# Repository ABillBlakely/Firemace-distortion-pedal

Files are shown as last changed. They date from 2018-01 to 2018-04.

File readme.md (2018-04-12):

# Firemace

## The Project:

Distortion pedals are one of the most basic and most used types of guitar effects pedal, and this project serves as a good introduction into the world of guitar effects building.
The Firemace is based on [Robin Tomtlunds Red Fuzz](http://www.generalguitargadgets.com/effects-projects/distortion/red-fuzz/) design.
This project is designed to be an easy to build kit with possibility of modification and customization.

## The Objective:

Learn the inner workings of distortion pedals, and the common techniques involved in building most guitar effect pedals.
Build your skills in circuit assembly and circuit analysis, and use your creativity to personalize the pedal.
The project builds skills including op-amp and transistor analysis, soldering, enclosure building.
Along the way you will get an introduction to PCB design, electronics prototyping, electronic components, common circuit blocks, time and frequency domain analysis.

## This repository

While you are here, check out the [schematic](firemace-schematic.pdf), the potential [modifications](modifications/), or view the PCB [front](firemace-pcb-front.png) and [back](firemace-pcb-back.png). You can also get the [bill of materials](firemace-BOM.xlsx).

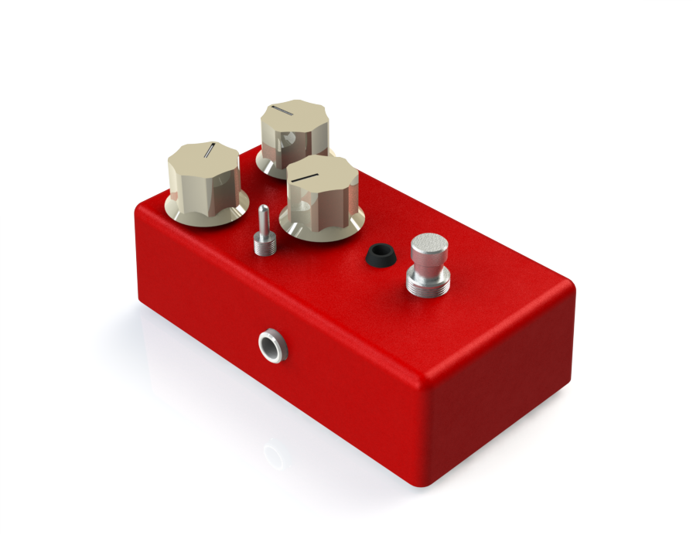
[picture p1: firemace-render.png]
Firemace render


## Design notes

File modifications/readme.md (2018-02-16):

# Modification Ideas

## Diode Swapping

The most basic, and probably most useful modification would be to swap out the clipping diodes (D3 & D4 or D5 & D6) for another type. Consider installing a socket for at least one of the clipping combinations for easy swapping.

Some ideas:

Stack 2 1n4148 diodes in series instead of the single that are in there now. This should make the volume difference between the silicon and LED clip selection close to equal.

Different types of silicon diodes may have subtly different characteristic. Try a big power diode like a 1n4007 in place of the 1n4148. While all silicon diodes should clip at the same voltage, the parasitic properties like on resistance and junction capacitance might change the sound.

You can put different diodes for each direction to make an assymetrical clip characteristic. Try a silicon diode one way and an led the other. Different colors of LED's should clip at slightly different voltages for a subtle asymmetry.

Germanium will clip at an even lower voltage than silicon, and this will come through a very compressed character. It will also be pretty quiet relative to other semiconductors.

Tons of possibilities here, Schottky diodes, zener diodes (forward or backwards biased), diode connected mosfets, or remove the diodes entirely and let the op amp clip itself for maximum volume.

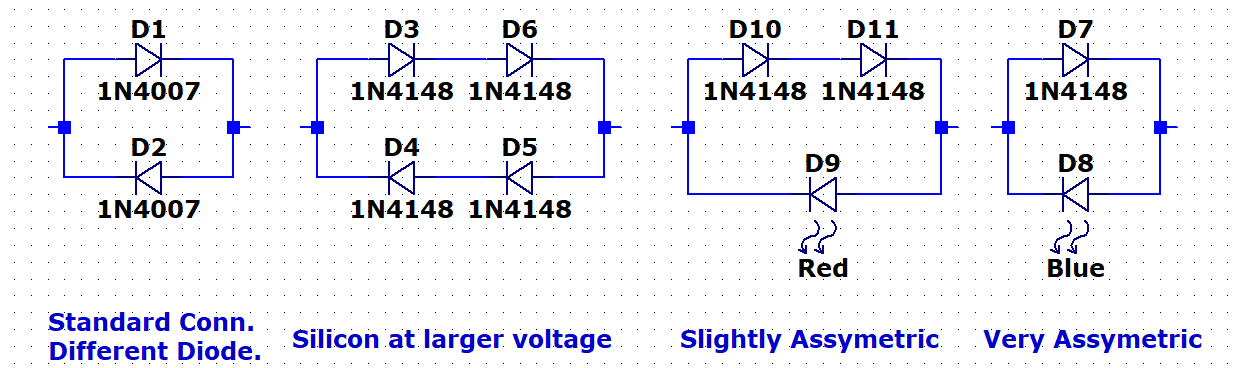
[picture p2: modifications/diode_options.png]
Diode configurations


## Filter Changes
C4 sets the low frequency cutoff according to 1/(2 * pi * 1800 * C)
The stock setting puts the rolloff at 400 Hz. If you feel it is lacking in the low end, try swapping this cap for the next size up. Or several sizes up. It's pretty hard to predict the frequency cutoff that will sound good, so just experiment.

## Additional Op amp Section
The NJM4580D is a dual op amp, and we are only using one of the sections. You could replace the JFET buffer with an op amp buffer for a little different sound OR:

* Configure it as a summing amp, and use it to blend in the dry signal with the dirty signal. This could be especially useful for bass.

* Build a second stage of clipping, cascaded after the first for very thick distortion. maybe build a second stage that uses diode to ground style clipping (as opposed to diodes in the feedback loop the existing stage uses) Use a switch to give either side or both together.

* Build an active low pass filter for tighter control over the high end.

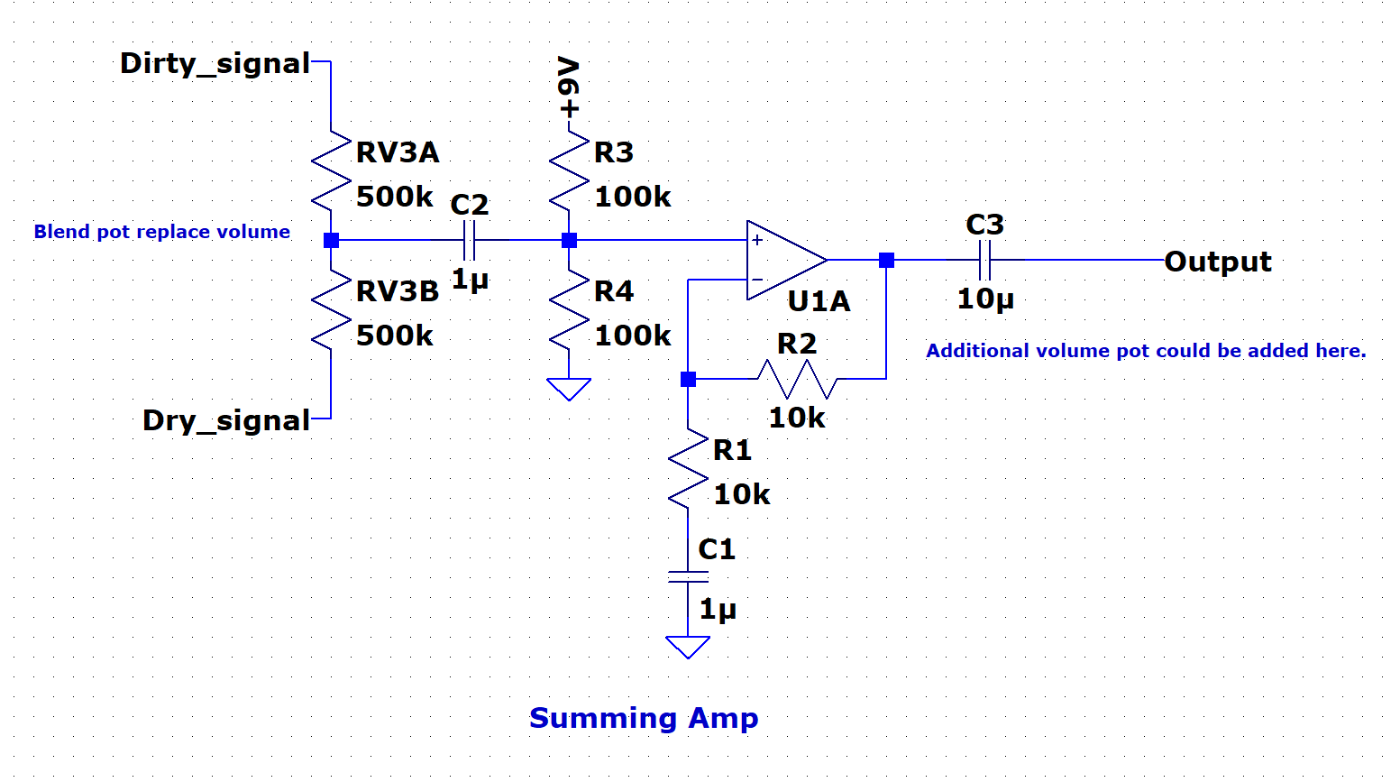
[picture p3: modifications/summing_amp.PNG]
Summing amp


## Swap the op amp.

The NJM4580D was chosen to go into slew rate distortion at the extreme settings. This technique is also used in the Rat distortion. Use a faster op amp like the NE5532 to avoid slew rate distortion. This is probably a pretty subtle change, but since the op amp is socketed, it is easy to try.

Slew rate is the maximum rate of change of an op amp usually expressed in V/us. The NJM4580D has a slew rate of 5 V/us while the NE5532 is 9 V/us. We can determine the frequency where slew rate limiting occurs by looking at the following:
* Maximum input level, A = 200 mV
* Maximum rate of change of sinusoid max(dV/dt) = max(d/dt(Asin(2 * pi * f * t)) = 2 * pi * f * A
* Maximum Gain of circuit (ignoring diodes, because max(dV/dt) occurs at the zero crossing.): G = 1 + (1Mohm +10kohm)/(1.8kohm) = 562

Combining these equations gives the maximum frequency without slew rate limiting.

SR = 2 * pi * f * A * G
f = SR / (2 * pi * A * G)
  = 5 x 10^6 V/s / (2 * pi * 0.2 V * 562)
  = 7 kHz.

We could recalculate and find, for instance, the gain where slew rate limiting occurs at 20kHz, or the input signal level that cause slew rate limiting at a particular frequency.

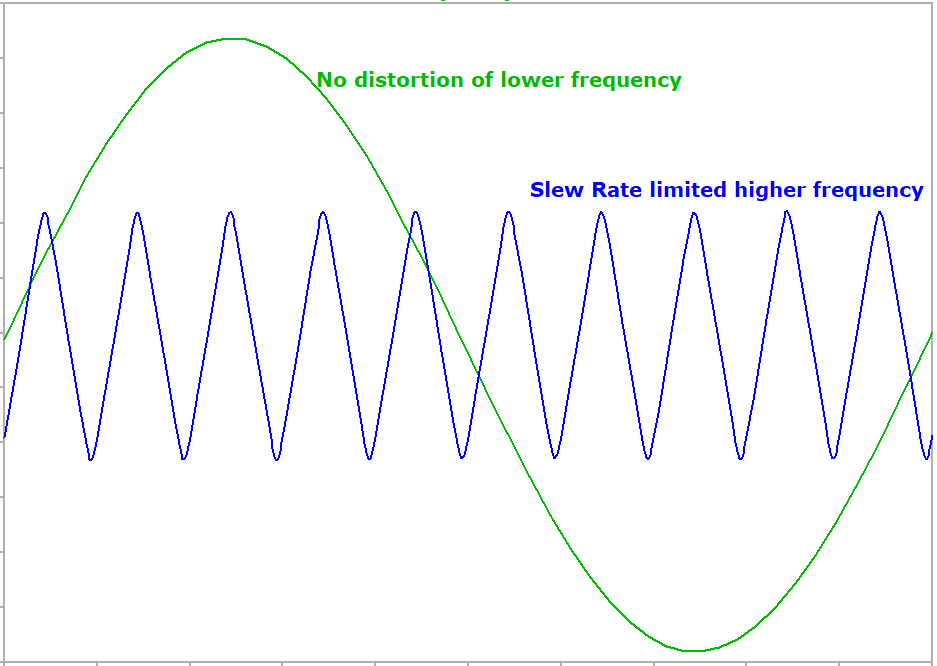
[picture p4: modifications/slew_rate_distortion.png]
Slew rate distortion


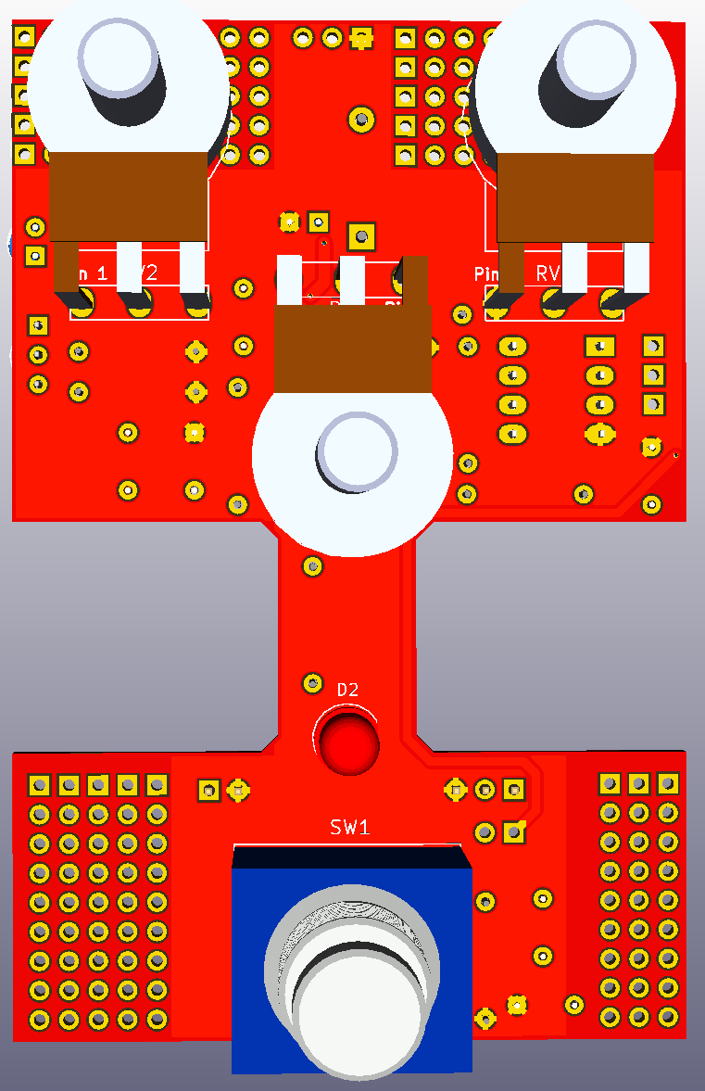
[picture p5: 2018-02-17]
firemace-pcb-back.png

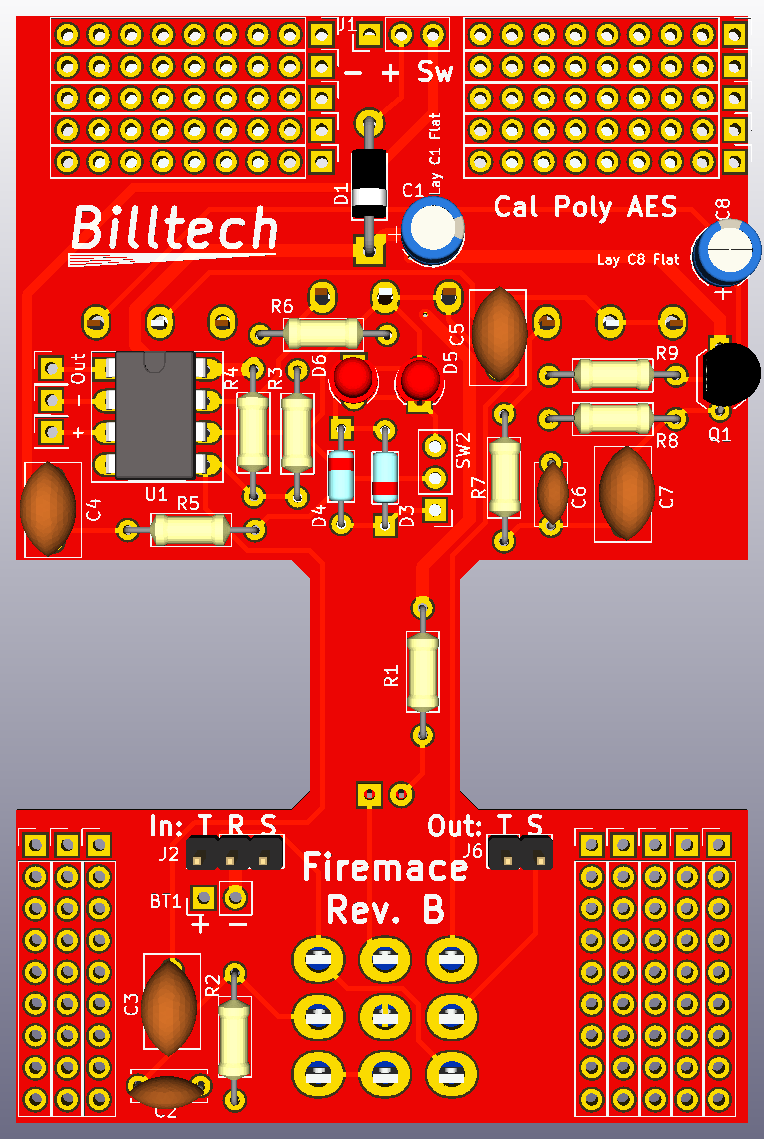
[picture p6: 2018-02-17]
firemace-pcb-front.png

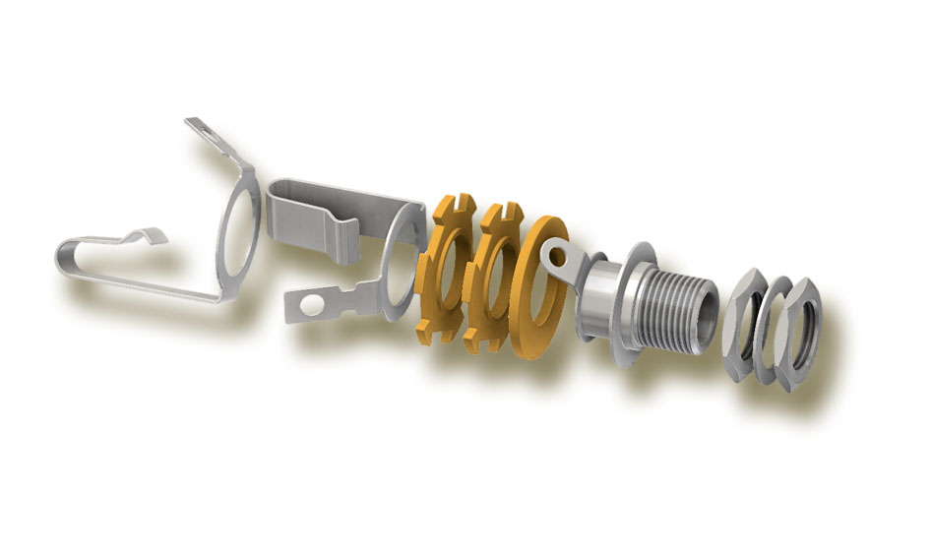
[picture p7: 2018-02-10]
solidworks-firemace/guitar input jack/InputJack Exploded2.jpg

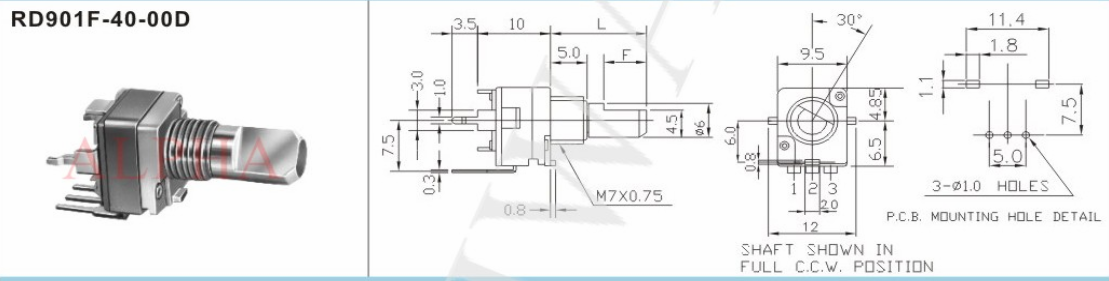
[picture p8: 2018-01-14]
refs/Alpha rd901f-40-00D.PNG

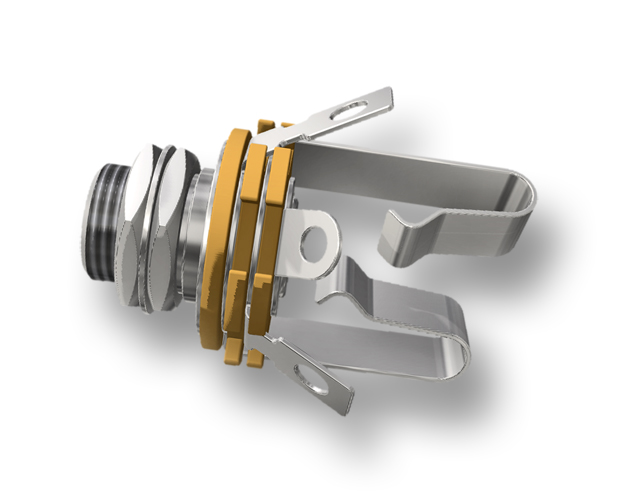
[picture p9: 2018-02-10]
solidworks-firemace/guitar input jack/Renderings/InputJack4.jpg

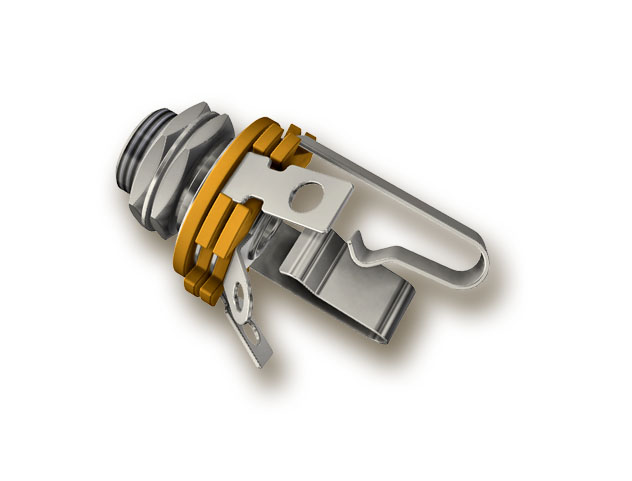
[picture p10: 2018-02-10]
solidworks-firemace/guitar input jack/InputJack3.jpg

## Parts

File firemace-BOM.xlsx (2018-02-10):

Supplier | Reference | Product | Price | Quantity | Total
SmallBear | C6 | Polyester Film Capacitors 0.0033uf : Topmay TMC05 | $0.25 | 1 | $0.25
SmallBear | C4 | Polyester Film Capacitors 0.22uf : Topmay TMC05 | $0.25 | 1 | $0.25
SmallBear | C3 | Polyester Film Capacitors 0.047uf : Topmay TMC05 | $0.25 | 1 | $0.25
SmallBear | C2 | Polyester Film Capacitors 0.001uf : Topmay TMC05 | $0.25 | 1 | $0.25
SmallBear | C5 | Polyester Film Capacitors 0.1uf : Topmay TMC05 | $0.25 | 2 | $0.50
SmallBear | C7 | Electrolytic Capacitors 10uF | $0.25 | 1 | $0.25
SmallBear | C1 | Electrolytic Capacitors 100uF | $0.35 | 1 | $0.35
SmallBear | D5 D6 | 3mm LED - Red | $0.25 | 2 | $0.50
SmallBear | D2 | 5mm LED - Red | $0.50 | 1 | $0.50
SmallBear | D1 | 1N5818 (Schottky Diode) | $0.15 | 1 | $0.15
SmallBear | D3 D4 | 1N4148 Small Signal Diode | $0.15 | 2 | $0.30
BLMS | J1 | 2.1mm DC Power Jack Solder Lug External Nut | $0.55 | 1 | $0.55
SmallBear | J2 | Stereo Open frame Jack Electronics | $1.25 | 1 | $1.25 | Slightly cheaper at BLMS, but out of stock
SmallBear | J6 | Mono Open frame Jack Electronics | $1.15 | 1 | $1.15 | Slightly cheaper at BLMS, but out of stock
BLMS | SW2 | SPDT On-On Solder Lug Toggle Switch | $0.74 | 1 | $0.74
BLMS | SW1 | 3PDT Stomp solder lug | $2.18 | 1 | $2.18
SmallBear | R5 R7 | Bag of 100 - 1/4 Watt Metal Film Resistor - 1.8K ohms | $2.00 | 0.02 | $0.04
SmallBear | R1 R6 R9 | Bag of 200 - 1/4 Watt Metal Film Resistor - 10K ohms | $3.95 | 0.015 | $0.06
SmallBear | R3 R4 | Bag of 100 - 1/4 Watt Metal Film Resistor - 470K ohms | $2.00 | 0.02 | $0.04
SmallBear | R2 R8 | Bag of 200 - 1/4 Watt Metal Film Resistor - 1.0M ohms | $3.95 | 0.01 | $0.04
SmallBear | RV2 | Alpha Potentiometer Linear (B)16mm Single Gang PCB Mount 90Â° Long Pin - B100K | $1.25 | 1 | $1.25
SmallBear | RV3 | Alpha Potentiometer Logarithmic (A)16mm Single Gang PCB Mount 90Â° Long Pin - A100K | $1.25 | 1 | $1.25
SmallBear | RV1 | Alpha Potentiometer Logarithmic (A)16mm Single Gang PCB Mount 90Â° Long Pin - A1M | $1.25 | 1 | $1.25
SmallBear | U1 | NJM4580D (IC) | $0.55 | 1 | $0.55
SmallBear | Q1 | J201 N-Channel JFET General Purpose Amplifier Transistor | $0.59 | 1 | $0.59
SmallBear | Enclosure | 125B(4.77 x 2.6 x 1.39) Painted | $6.25 | 1 | $6.25
SmallBear | Knobs | Large Fluted MXR Style Colored | $0.80 | 3 | $2.40
SmallBear | DIP-8 Socket | DIP-8 Socket | $0.64 | 1 | $0.64
SmallBear | SIP socket | SIP20 Socket Snap-off | $2.50 | 0.15 | $0.38
BLMS | LED Bezel | Bag of 5 5mm LED Bezel Black | $1.25 | 0.2 | $0.25
SmallBear | Batt Snap | T-style 9V | $0.35 | 1 | $0.35
SmallBera | Batt | 9V Battery | $2.15 | 1 | $2.15
Shipping Small bear | Shipping | Fedex for order of 10 | $30.00 | 0.1 | $3.00
BLMS | Shipping |  | $6.95 | 0.1 | $0.70
SeeedStudio | PCB | Set of 20 incl. shipping | $31.42 | 0.05 | $1.57
 |  |  |  | Total | $32.17
 |  |  |  | Plus tax | $34.82
 |  |  |  | Plus FUA | $41.79

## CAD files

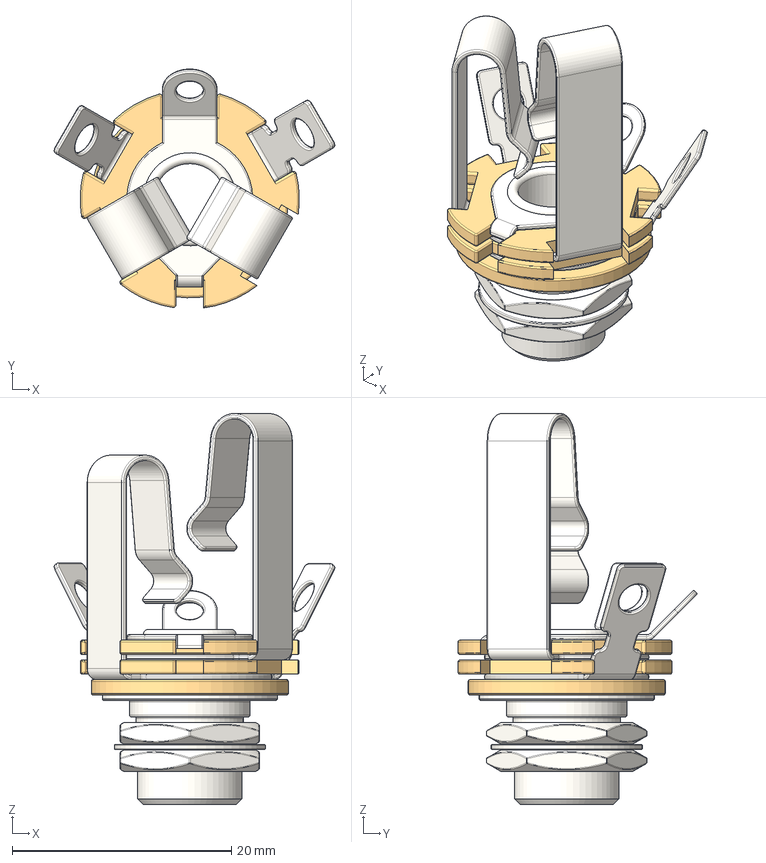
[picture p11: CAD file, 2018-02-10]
solidworks-firemace/guitar input jack/InputJack_Cover_Assembly.stp
25.6 x 21.8 x 35.7 mm
InputJack_shield
InputJack_partition1
InputJack_partition2 x 2
InputJack_nut x 2
InputJack_Washer
InputJack_signal2
InputJack_signal1

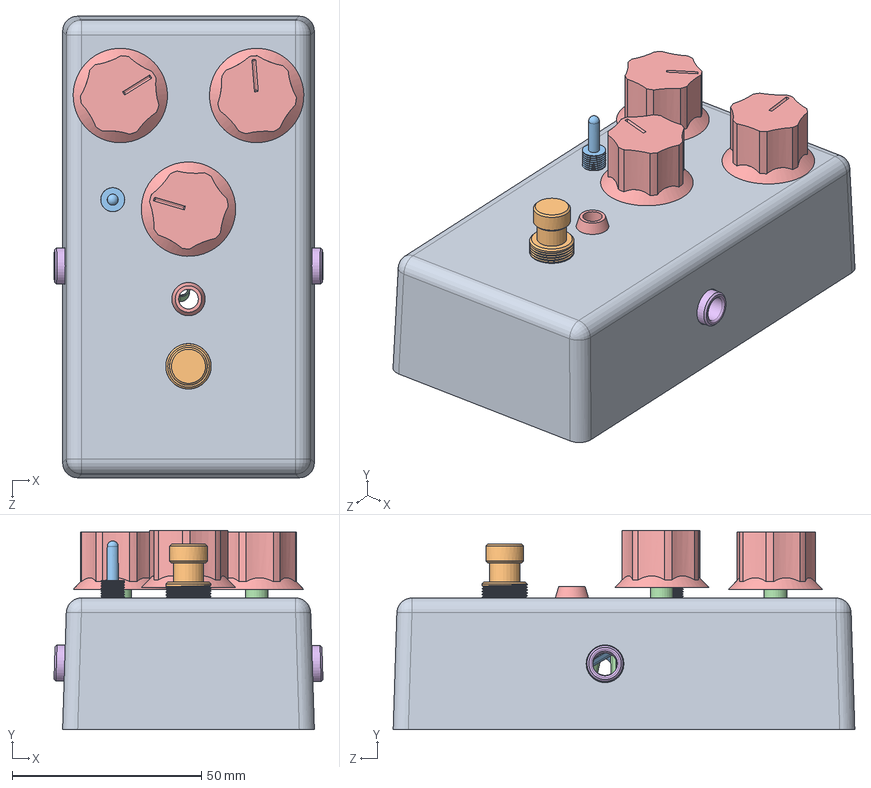
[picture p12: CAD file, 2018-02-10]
solidworks-firemace/firemace assembly.SLDASM
71.0 x 52.7 x 121.9 mm
enclosure
switch 3pdt stomp solder lug
spst switch
Pot 16mm long lead x 3
knob mxr 25.3mm x 3
Copy of InputJack_shield.ipt^Copy of InputJack_Assembly.iam_firemace assembly x 2
Copy of InputJack_partition1.ipt^Copy of InputJack_Assembly.iam_firemace assembly x 2
Copy of InputJack_partition2.ipt^Copy of InputJack_Assembly.iam_firemace assembly x 4
Copy of InputJack_nut.ipt^Copy of InputJack_Assembly.iam_firemace assembly x 4
Copy of InputJack_Washer.ipt^Copy of InputJack_Assembly.iam_firemace assembly x 2
Copy of InputJack_signal2.ipt^Copy of InputJack_Assembly.iam_firemace assembly x 2
Copy of InputJack_signal1.ipt^Copy of InputJack_Assembly.iam_firemace assembly x 2
led bezel

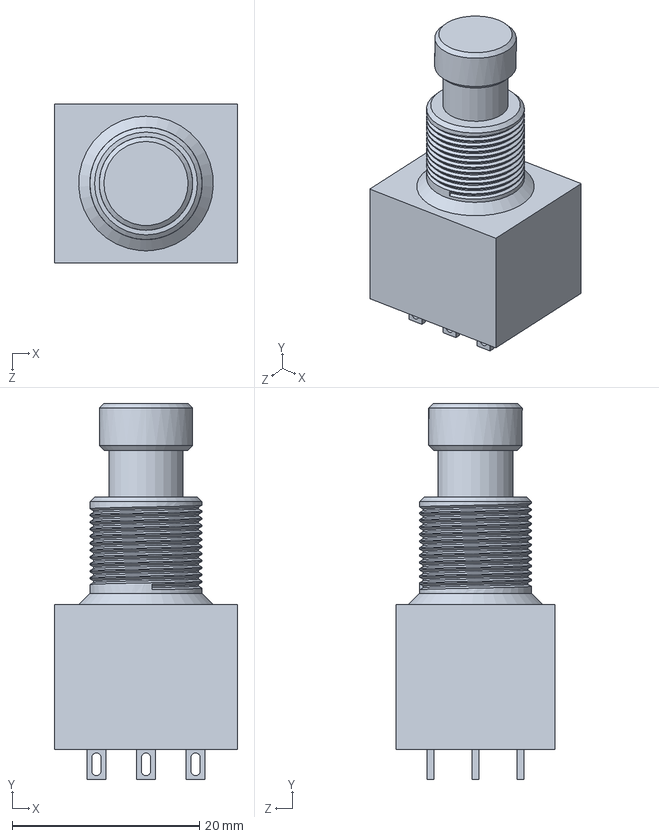
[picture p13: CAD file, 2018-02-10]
solidworks-firemace/switch 3pdt stomp solder lug.SLDPRT
19.6 x 40.2 x 17.0 mm

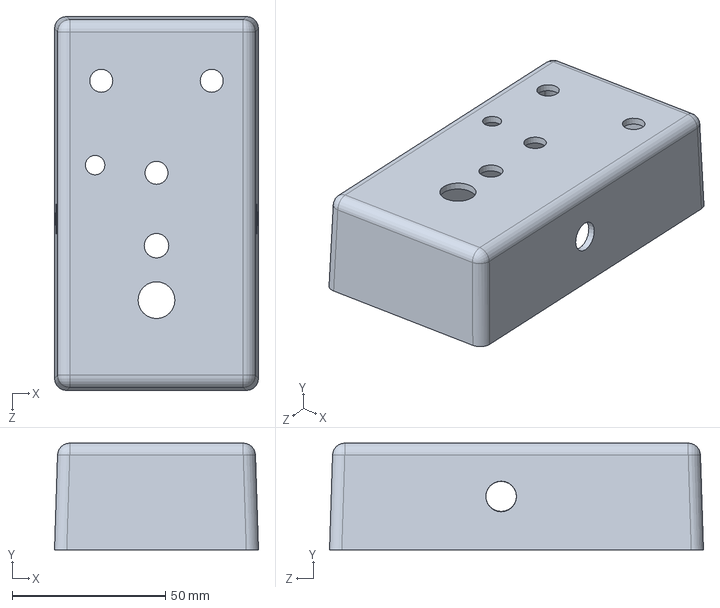
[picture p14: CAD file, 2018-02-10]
solidworks-firemace/enclosure.SLDPRT
66.5 x 34.8 x 121.9 mm

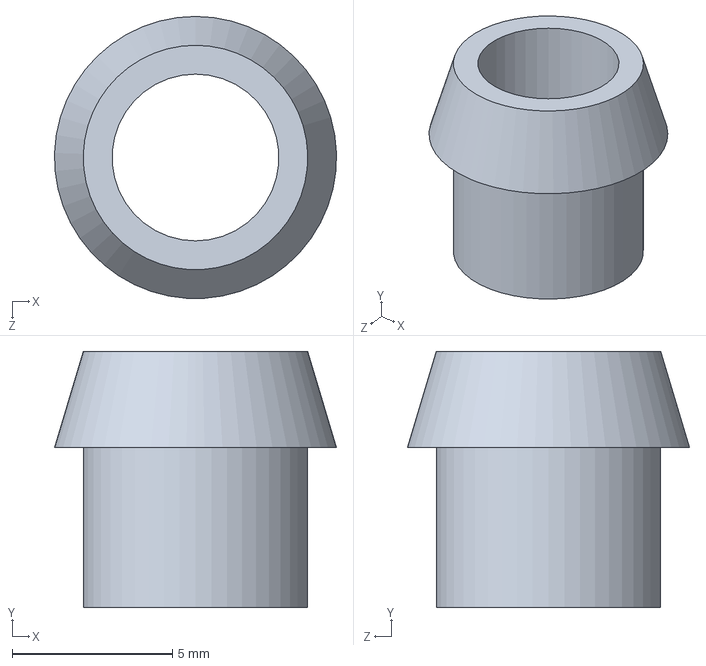
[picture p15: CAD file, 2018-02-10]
solidworks-firemace/led bezel.SLDPRT
8.80 x 8.00 x 8.80 mm

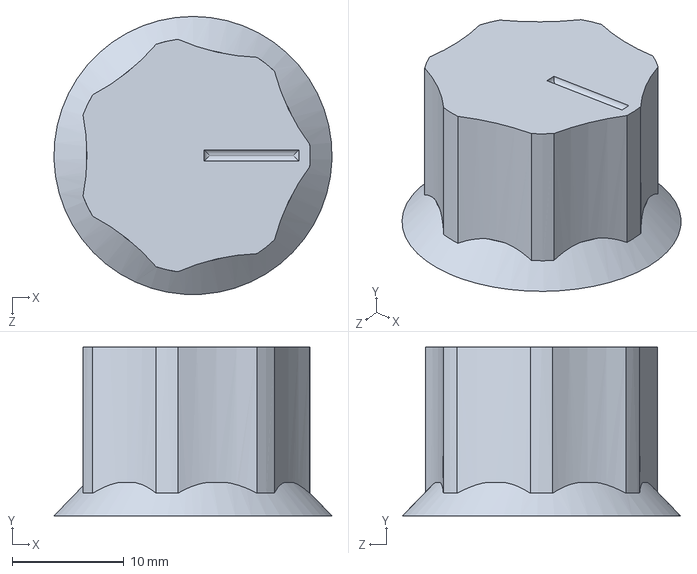
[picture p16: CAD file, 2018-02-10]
solidworks-firemace/knob mxr 25.3mm.SLDPRT
24.9 x 15.1 x 24.9 mm

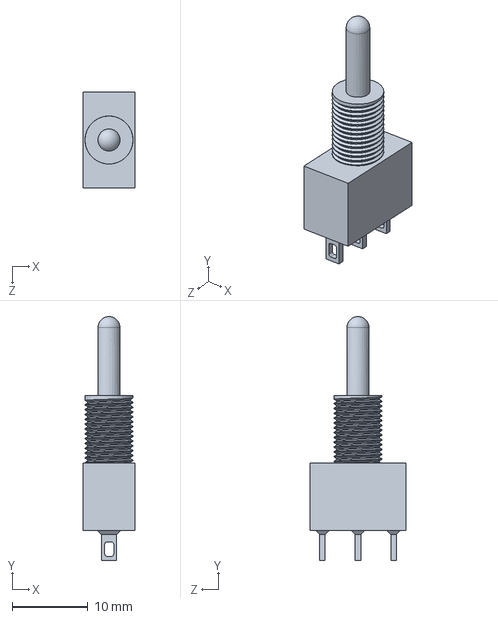
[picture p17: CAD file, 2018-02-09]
solidworks-firemace/spst switch.SLDPRT
6.86 x 32.1 x 12.7 mm

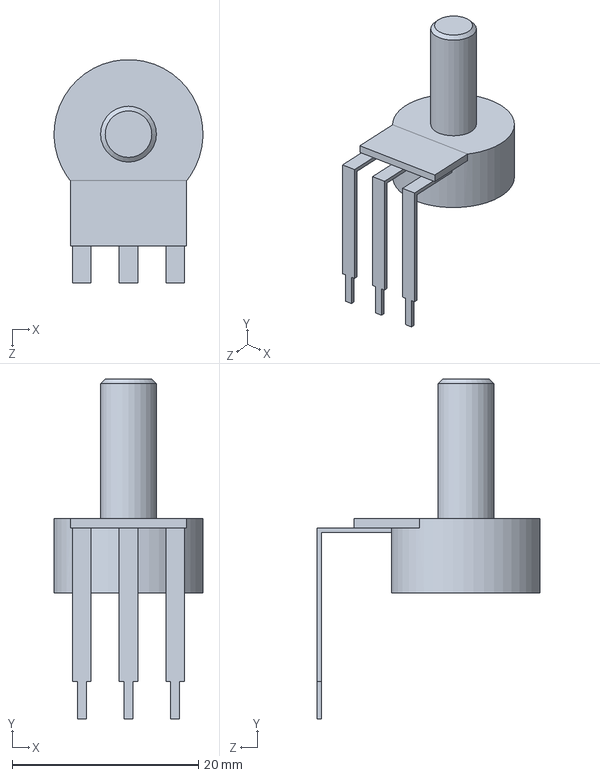
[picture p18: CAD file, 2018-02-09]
solidworks-firemace/Pot 16mm long lead.SLDPRT
16.0 x 36.5 x 24.0 mm

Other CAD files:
solidworks-firemace/Pot 16mm long lead.STL
solidworks-firemace/guitar input jack/InputJack_Assembly.iam
solidworks-firemace/guitar input jack/InputJack_Cover_Assembly.igs
solidworks-firemace/guitar input jack/InputJack_Cover_Assembly.stl
solidworks-firemace/guitar input jack/InputJack_Washer.ipt
solidworks-firemace/guitar input jack/InputJack_nut.ipt
solidworks-firemace/guitar input jack/InputJack_partition1.ipt
solidworks-firemace/guitar input jack/InputJack_partition2.ipt
solidworks-firemace/guitar input jack/InputJack_shield.ipt
solidworks-firemace/guitar input jack/InputJack_signal1.ipt
solidworks-firemace/guitar input jack/InputJack_signal2.ipt

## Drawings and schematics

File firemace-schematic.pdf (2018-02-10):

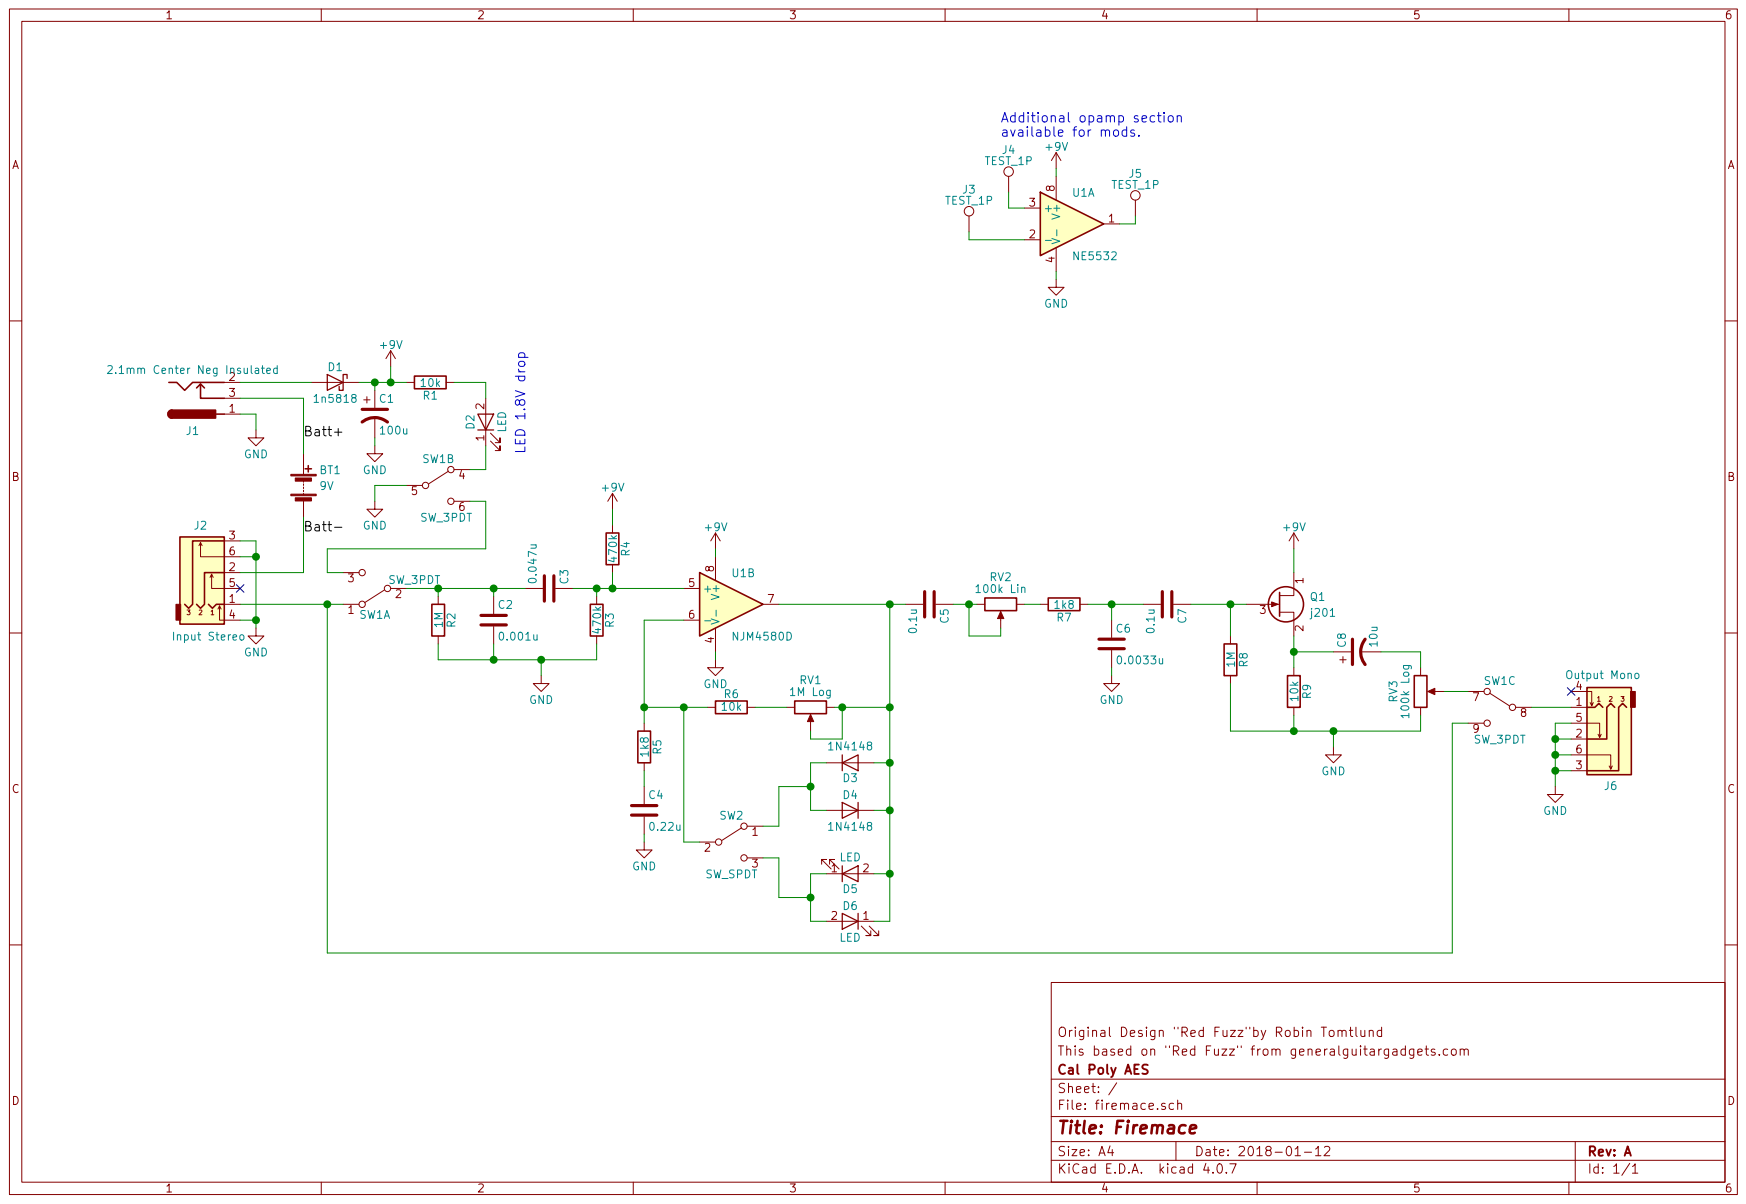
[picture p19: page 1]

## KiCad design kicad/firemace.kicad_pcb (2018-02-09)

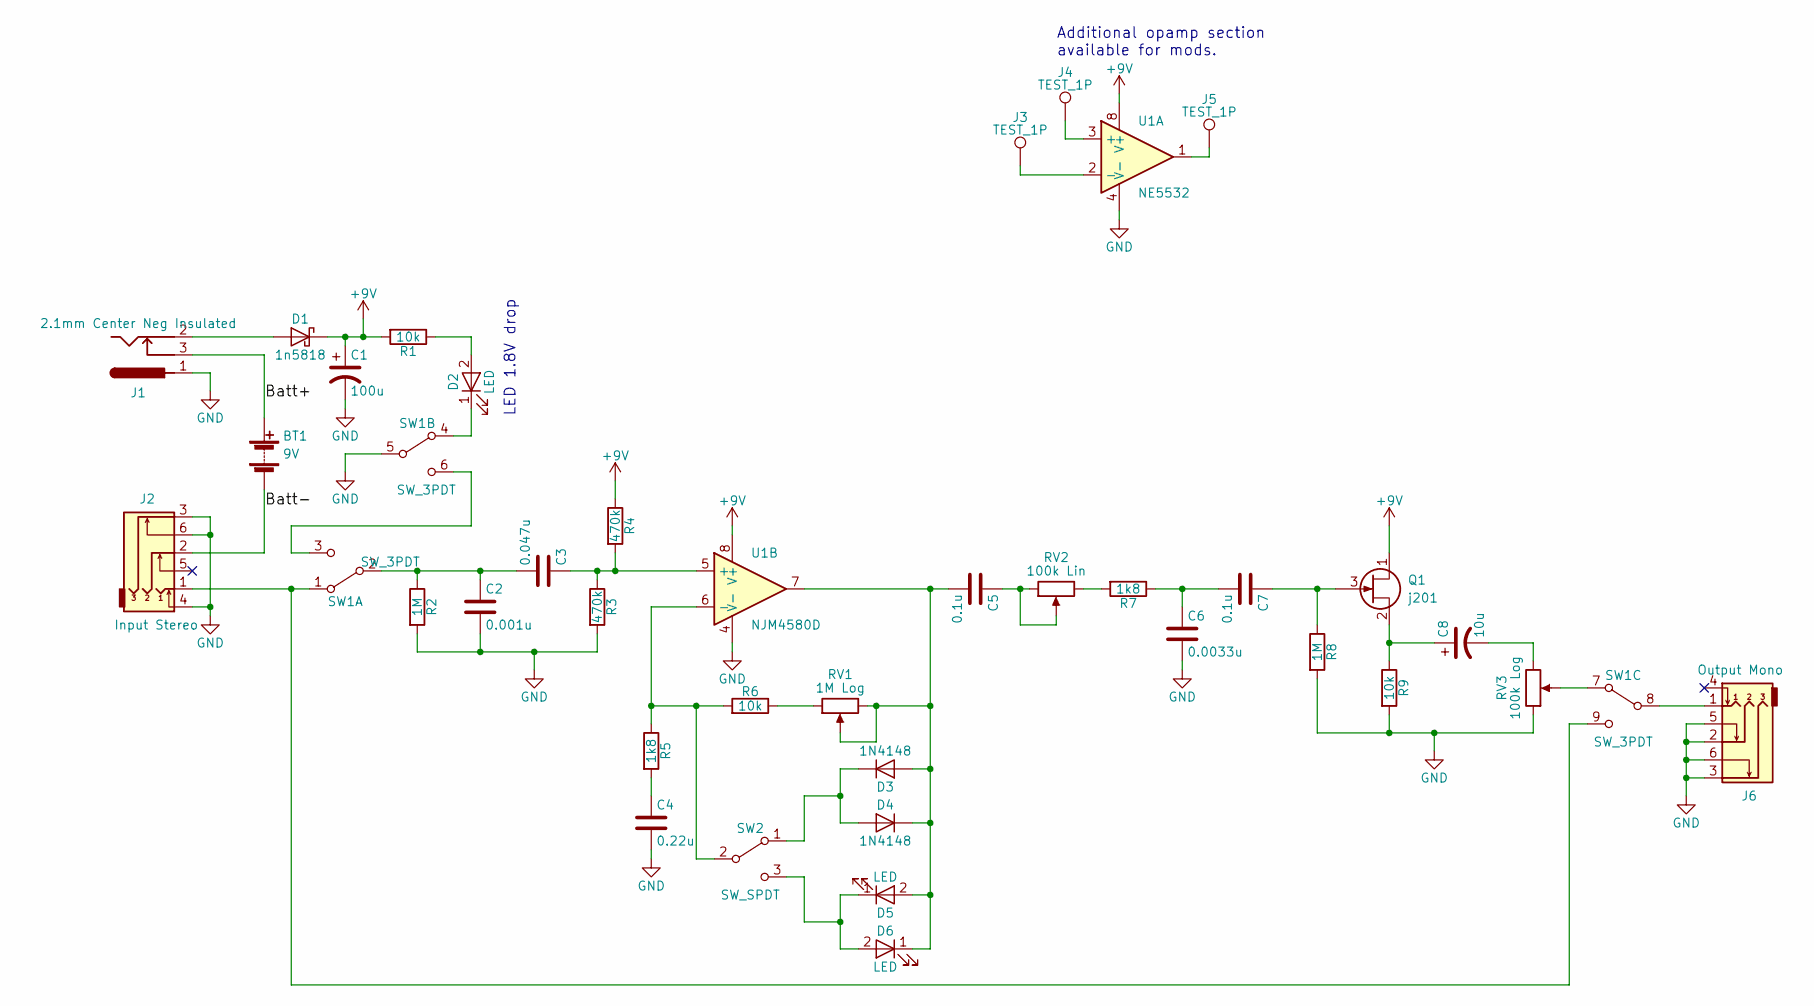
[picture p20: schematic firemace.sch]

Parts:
BT1: 9V; Pin_Header_Straight_1x02_Pitch2.54mm
C1: 100u; CP_Radial_D5.0mm_P2.50mm
C2: 0.001u; C_Disc_D6.0mm_W2.5mm_P5.00mm
C3: 0.047u; C_Disc_D7.5mm_W4.4mm_P5.00mm
C4: 0.22u; C_Disc_D7.5mm_W4.4mm_P5.00mm
C5, C7: 0.1u; C_Disc_D7.5mm_W4.4mm_P5.00mm
C6: 0.0033u; C_Disc_D5.0mm_W2.5mm_P5.00mm
C8: 10u; CP_Radial_D5.0mm_P2.50mm
D1: 1n5818; D_DO-41_SOD81_P10.16mm_Horizontal
D2: LED; LED_D5.0mm
D3, D4: 1N4148; D_DO-35_SOD27_P7.62mm_Horizontal
D5, D6: LED; LED_D3.0mm
J1: 2.1mm Center Neg Insulated; Pin_Header_Straight_1x03_Pitch2.54mm
J2: Input Stereo; Pin_Header_Straight_1x03_Pitch2.54mm
J3, J4, J5: TEST_1P; Pin_Header_Straight_1x01_Pitch2.54mm
J6: Output Mono; Pin_Header_Straight_1x02_Pitch2.54mm
Q1: j201; TO-92_Inline_Wide
R1, R6, R9: 10k; R_Axial_DIN0207_L6.3mm_D2.5mm_P10.16mm_Horizontal
R2, R8: 1M; R_Axial_DIN0207_L6.3mm_D2.5mm_P10.16mm_Horizontal
R3, R4: 470k; R_Axial_DIN0207_L6.3mm_D2.5mm_P10.16mm_Horizontal
R5, R7: 1k8; R_Axial_DIN0207_L6.3mm_D2.5mm_P10.16mm_Horizontal
RV1: 1M Log; pot_16mm_long_lead
RV2: 100k Lin; pot_16mm_long_lead
RV3: 100k Log; pot_16mm_long_lead
SW1: SW_3PDT; 3PDT_Solder_Lugs
SW2: SW_SPDT; Pin_Header_Straight_1x03_Pitch2.54mm
U1: NJM4580D; DIP-8_W7.62mm_Socket_LongPads

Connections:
+9V: C1.1, D1.1 (K), Q1.1 (D), R1.2, R4.1, U1.8 (V+)
/Batt+: BT1.1 (+), J1.3
/Batt-: BT1.2 (-), J2.2
GND: C1.2, C2.2, C4.2, C6.2, J1.1, J2.3, J2.4, J2.6, J6.2, J6.3, J6.5, J6.6, R2.2, R3.2, R8.2, R9.2, RV3.1, SW1.5 (B), U1.4 (V-)
unnamed: C2.1, C3.2, R2.1, SW1.2 (B)
unnamed: C3.1, R3.1, R4.2, U1.5 (+)
unnamed: C4.1, R5.2
unnamed: C5.1, RV2.1, RV2.2
unnamed: C5.2, D3.2 (A), D4.1 (K), D5.2 (A), D6.1 (K), RV1.2, RV1.3, U1.7
unnamed: C6.1, C7.2, R7.1
unnamed: C7.1, Q1.3 (G), R8.1
unnamed: C8.1, Q1.2 (S), R9.1
unnamed: C8.2, RV3.3
unnamed: D1.2 (A), J1.2
unnamed: D2.1 (K), SW1.4 (A)
unnamed: D2.2 (A), R1.1
unnamed: D3.1 (K), D4.2 (A), SW2.1 (A)
unnamed: D5.1 (K), D6.2 (A), SW2.3 (C)
unnamed: J2.1, SW1.1 (A), SW1.9 (C)
unnamed 19: J3.1, U1.2 (-); also elsewhere on the board
unnamed 20: J4.1, U1.3 (+); also elsewhere on the board
unnamed 21: J5.1, U1.1; also elsewhere on the board
unnamed: J6.1, SW1.8 (B)
unnamed: R5.1, R6.2, SW2.2 (B), U1.6 (-)
unnamed: R6.1, RV1.1
unnamed: R7.2, RV2.3
unnamed: RV3.2, SW1.7 (A)
unnamed: SW1.3 (C), SW1.6 (C)

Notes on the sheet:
Additional opamp section available for mods.
LED 1.8V drop

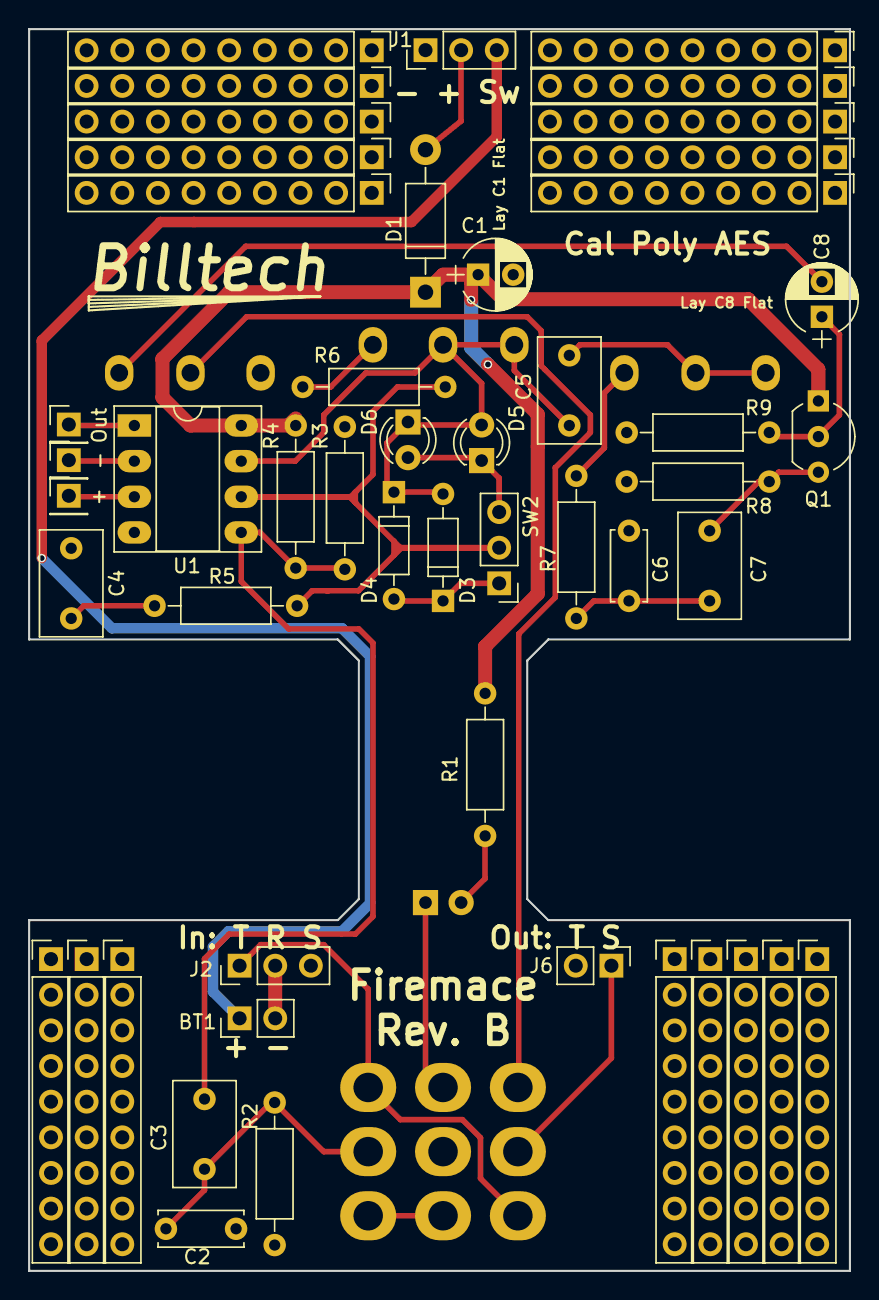
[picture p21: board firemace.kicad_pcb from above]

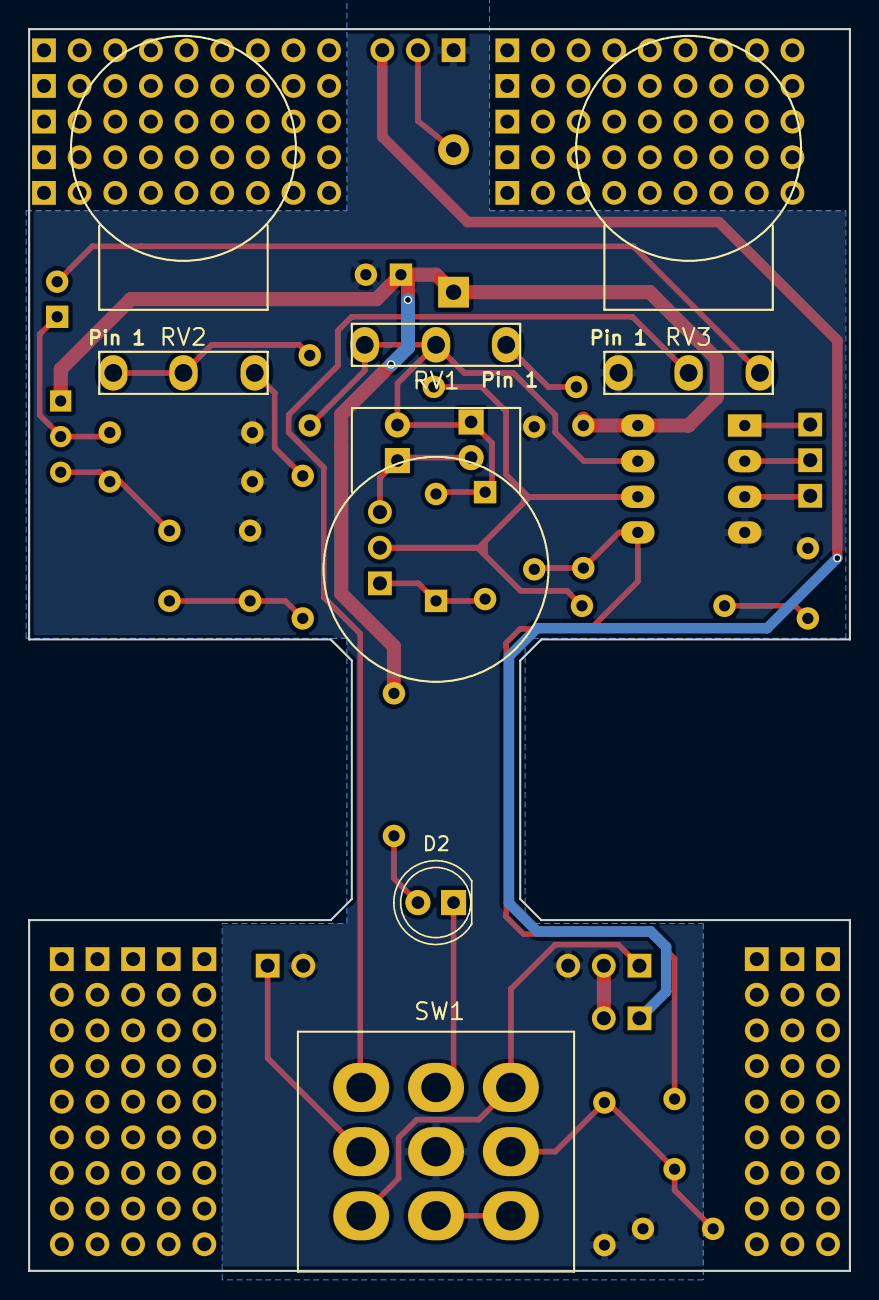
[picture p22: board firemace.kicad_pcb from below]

Board: 2 copper layers, 58.5 x 88.5 mm, 37 parts (5 on the bottom side), 28 nets.

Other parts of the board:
+: TEST_1P; Pin_Header_Straight_1x01_Pitch2.54mm
-: TEST_1P; Pin_Header_Straight_1x01_Pitch2.54mm
Out: TEST_1P; Pin_Header_Straight_1x01_Pitch2.54mm

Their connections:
unnamed 19: -.1; also elsewhere on the board
unnamed 20: +.1; also elsewhere on the board
unnamed 21: Out.1; also elsewhere on the board

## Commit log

2018-01-14 PCB design prototype for AES pedal kit.
    [red-fuzz.kicad_pcb, red-fuzz.sch]
2018-02-09 Project Rev. B
    [Pot 16mm long lead.SLDPRT, Pot 16mm long lead.STL, drill template.SLDDRW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]
2018-02-10 minor changes to match available supply. Add new BOM.
    [knob mxr 25.3mm.SLDPRT, red-fuzz assembly.SLDASM, red-fuzz-BOM.csv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]
2018-02-10 Create basic verison of led bezel.
    [led bezel.SLDPRT]
2018-02-10 Rename to firemace, add most of the missing parts from 3d model.
    [InputJack_Assembly.iam, InputJack_Cover_Assembly.igs, InputJack_Cover_Assembly.stl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]
2018-02-17 Move BOM to project root.
    [firemace-BOM.xlsx]
2018-02-17 Add pcb images, improve readme
2018-04-12 Correct a couple of typos.
